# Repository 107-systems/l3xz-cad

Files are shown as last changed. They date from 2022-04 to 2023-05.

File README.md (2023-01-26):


`l3xz_cad`
==========


Hardware design files for the L3X-Z hexapod.

<p align="center">
  
</p>

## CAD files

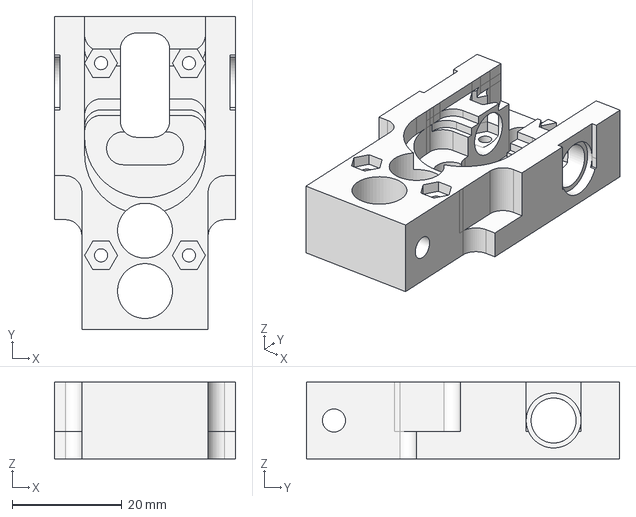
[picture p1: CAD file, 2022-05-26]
cad/dynamixel_joint.step
33.0 x 57.0 x 14.0 mm

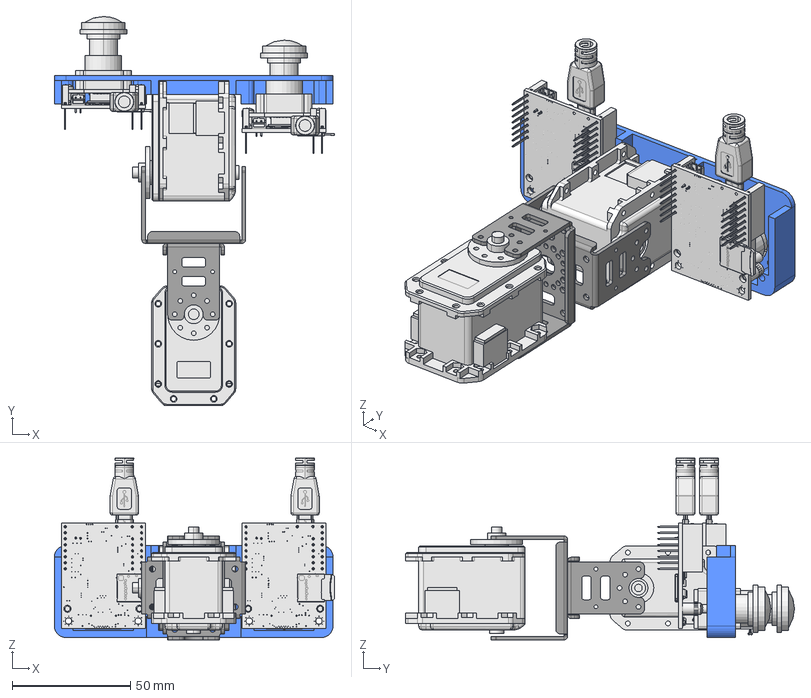
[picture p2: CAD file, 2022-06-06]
cad/pan_tilt_head/pan_tilt_head.FCStd
118.7 x 164.6 x 77.0 mm
DC07_A_DUMMY_AL
FR07-H101
FR07-H102
DC07_A_DUMMY_AL001
openmv4_h008
openmv4_h009
cam_holder001

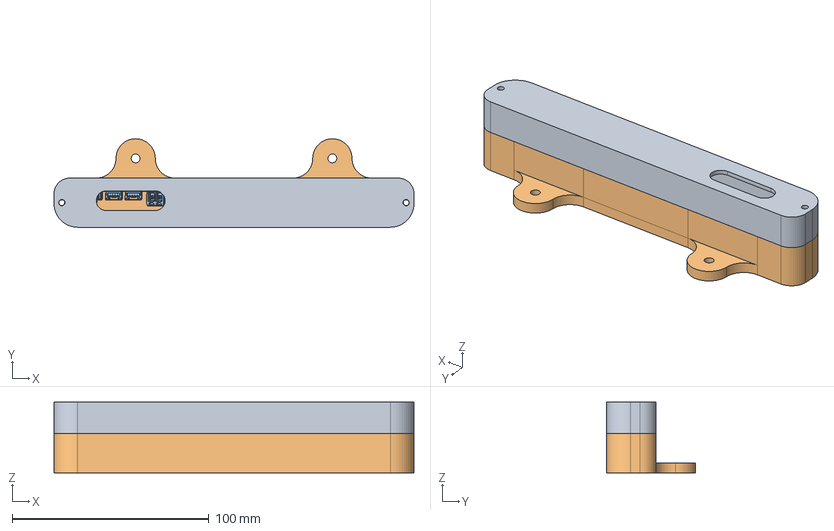
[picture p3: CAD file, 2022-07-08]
cad/radiation_sensor/radiation_sensor.FCStd
183.0 x 45.0 x 36.0 mm
radiation_sensor_top
radiation_sensor_bot
l3xz-hw_leg-controller

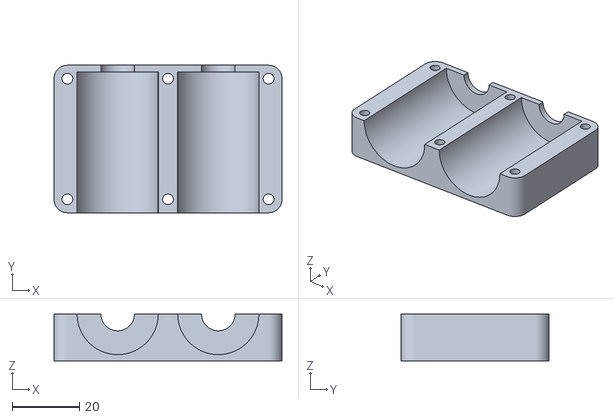
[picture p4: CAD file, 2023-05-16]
cad/stl_files/valve_mount.stl
68.0 x 44.0 x 14.0

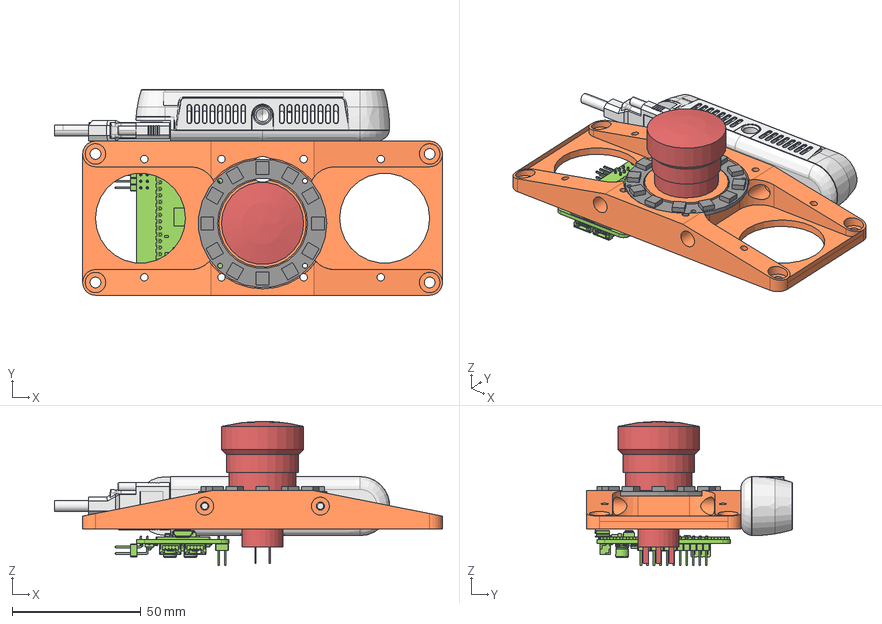
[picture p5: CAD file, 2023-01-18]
cad/upper_deck/upper_deck.FCStd
151.0 x 80.0 x 56.2 mm
Intel_RealSense_Depth_Camera_D415
upper_deck_plate
OpenCyphalPicoBase
Adafruit_Neopixel_12_50mm
TC-9219036

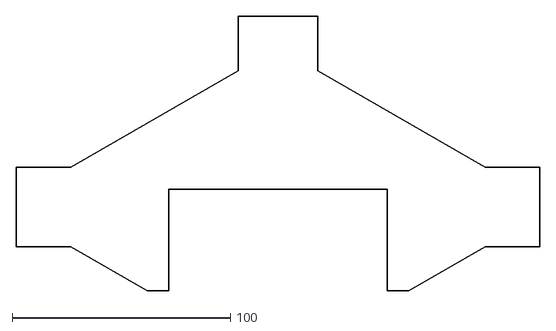
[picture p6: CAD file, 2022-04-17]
cad/body-bottom-front-bracket-base.dxf
240.0 x 125.9

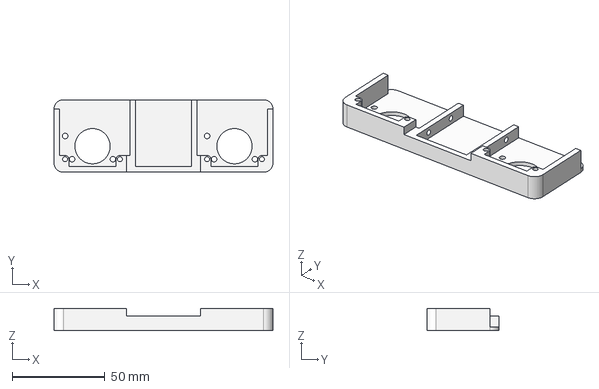
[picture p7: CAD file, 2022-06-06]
cad/pan_tilt_head/cam_holder.step
118.0 x 39.0 x 12.0 mm

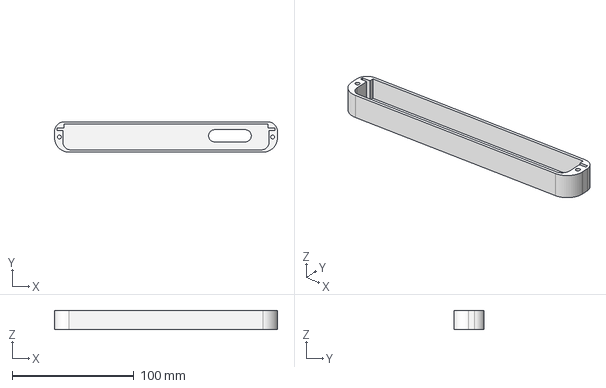
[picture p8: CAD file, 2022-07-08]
cad/radiation_sensor/radiation_sensor_top.step
183.0 x 25.0 x 16.0 mm

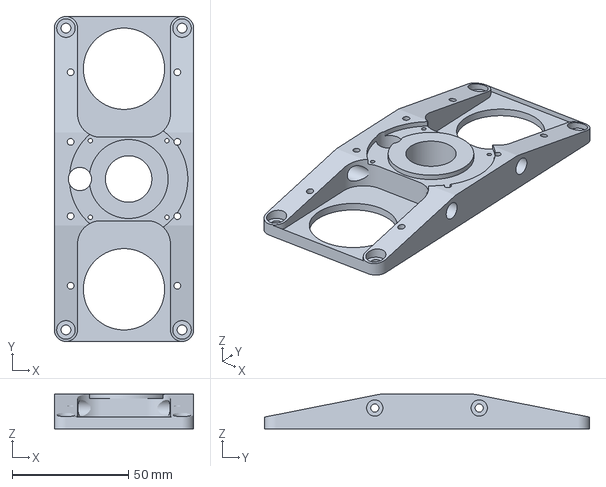
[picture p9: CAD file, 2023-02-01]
cad/stl_files/upper_deck_plate.3mf
60.0 x 140.0 x 15.0 mm

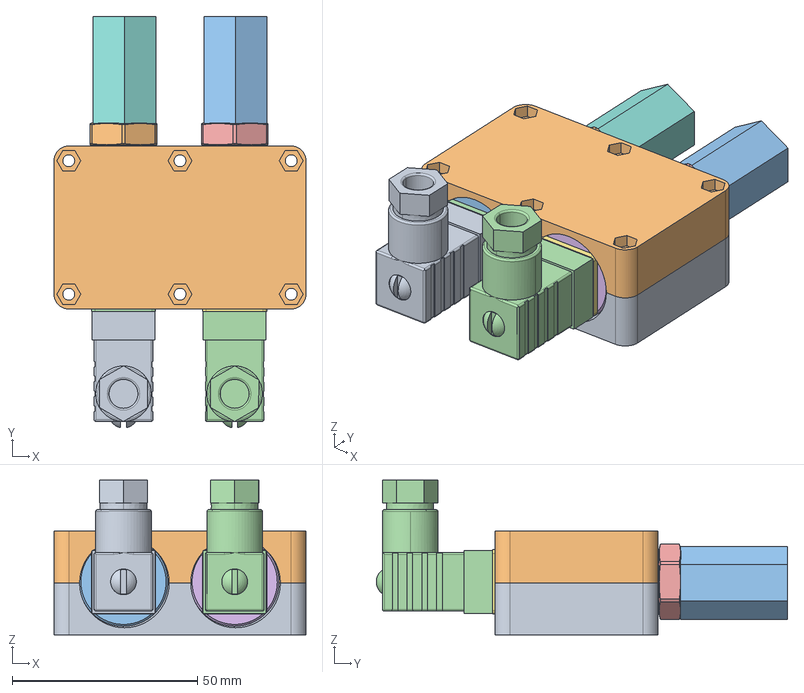
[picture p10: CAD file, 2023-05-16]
cad/valve_mount/valve_mount.FCStd
68.0 x 111.0 x 41.7 mm
Part (Mirror #1)
Small Din Connector - screw down version
B0877 iss 2
A1479 iss 2
Gasket
Small Din Connector - screw down version001
B0877 iss 003
A1479 iss 003
Gasket001

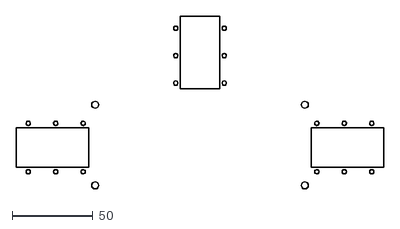
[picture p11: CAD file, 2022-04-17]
cad/body-bottom-front-bracket-holes.dxf
228.0 x 107.2

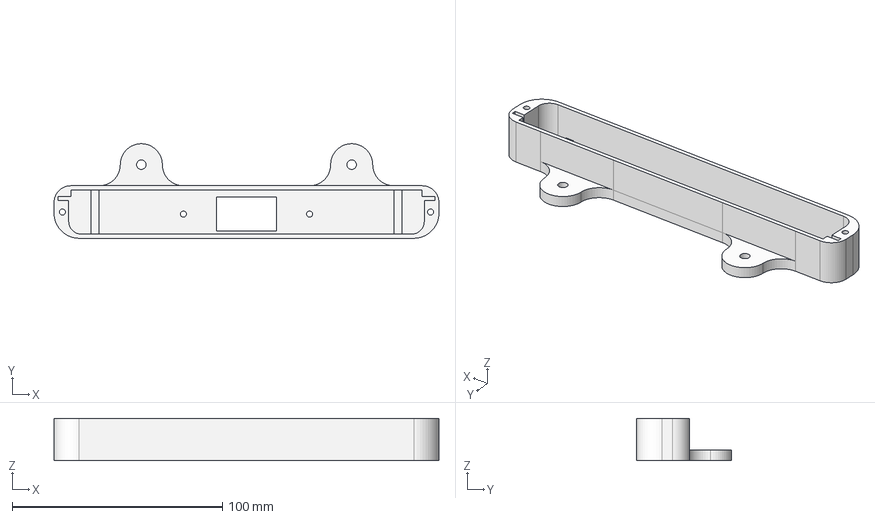
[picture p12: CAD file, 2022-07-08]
cad/radiation_sensor/radiation_sensor_bot.step
183.0 x 45.0 x 20.0 mm

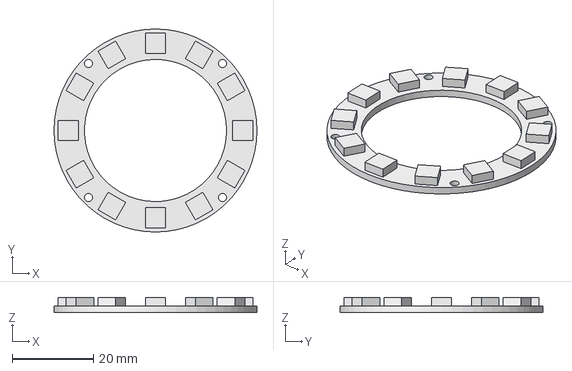
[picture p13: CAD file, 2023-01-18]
cad/upper_deck/Adafruit_Neopixel_12_50mm.step
50.0 x 50.0 x 3.60 mm

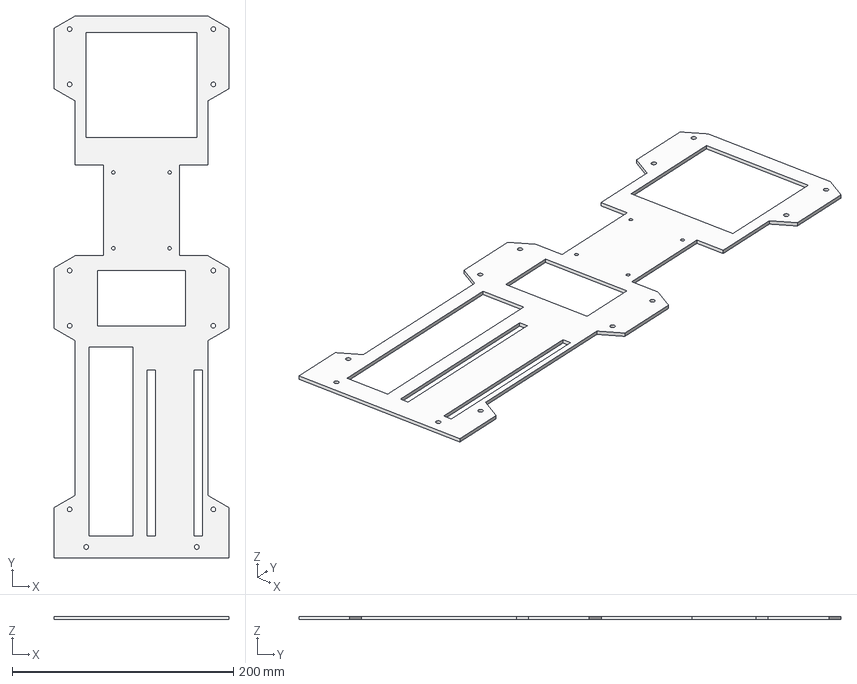
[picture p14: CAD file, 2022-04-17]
cad/top-bracket.step
158.0 x 490.2 x 3.00 mm

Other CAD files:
cad/upper_deck/upper_deck_plate.step
cad/stl_files/radiation_sensor_top.stl
cad/stl_files/radiation_sensor_bot.stl
cad/upper_deck/emergency_stop_TC-9219036.step
cad/0H108A.FCStd
cad/0H108A.step
cad/0H1650A.FCStd
cad/0H1650A.step
cad/0H506A.FCStd
cad/0H506A.step
cad/FR07-H101.stp
cad/LAS4GQH-11_S.FCStd
cad/LAS4GQH-11_S.step
cad/MX-28AT_AR.stp
cad/back-bracket.step
cad/body-bottom-back-bracket-base.dxf
cad/body-bottom-back-bracket-holes.dxf
cad/body-bottom-base.dxf
cad/body-bottom-holes.dxf
cad/body-bottom-middle-bracket-base.dxf
cad/body-bottom-middle-bracket-holes.dxf
cad/body-bottom-top-base.dxf
cad/body-bottom-top-holes.dxf
cad/body-bottom.FCStd
cad/body-bottom.step
cad/dynamixel_joint.FCStd
cad/femur.FCStd
cad/femur.step
cad/front-bracket.step
cad/l3xz.FCStd
cad/leg.FCStd
cad/leg.step
cad/middle-bracket.step
cad/pan_tilt_head/cam_holder.FCStd
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

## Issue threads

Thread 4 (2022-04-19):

ELROB Rules: Vehicle mounted Emergency Stop Unit and Warning Devices

generationmake, 2022-04-19:
https://www.elrob.org/files/elrob2022/ELROB2022_Rules_Draft.pdf

4.5.4 Vehicle mounted Emergency Stop Unit
Each vehicle must be additionally equipped with an externally actuated emergency stop capability.
Activating the emergency stop must promptly bring the vehicle into the E-stop mode, leading to an
immediate and complete stop. At least one actuator and its labelling must be easily visible and
accessible from anywhere around the vehicle. The manual emergency stop must be easy to identify
and to activate, even if the vehicle is moving at a walking pace. The operation instructions for
emergency stop actuators must be clearly labelled in English. The instructions must not be interfered
with by any other labelling or advertising.

4.5.5 Warning Devices
Each vehicle shall display one or more flashing amber warning lights, the combination of which
results in a visibility of 360 degrees azimuthally around the vehicle. The warning light(s) shall
continuously operate whenever the vehicle is switched on. The vehicle may not commence movement
until the warning light(s) have been in operation for 5 seconds.
The warning light(s) shall comply with standards for warning lights and shall not produce light that
can be confused with those of public safety vehicles such as law enforcement, fire or ambulance

Closed 2022-10-17.

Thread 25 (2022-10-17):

[Feature Request] CI - Fix spell check

aentinger, 2022-10-17:
<a href="https://107-systems.org/">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</a>

### ⚡ Feature Request

**Please Describe The Problem To Be Solved**
Due to an update of the of the spell checking action more cases are flagged than before. Address those or add the offending file to the ignore list.

aentinger, 2022-11-09:
Done by #27 .

Closed 2022-11-09.

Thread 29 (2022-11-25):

[Feature Request] Design for new pan/tilt head

aentinger, 2022-11-25:
<a href="https://107-systems.org/">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</a>

### ⚡ Feature Request

TODO ...

**Please Describe The Problem To Be Solved**

scottdarch, 2022-11-29:
Why a wireless version of the Pi Zero?

scottdarch, 2022-11-29:
Also, if reducing wire-weight is a concern then is 8-wire ethernet really going to help?

aentinger, 2022-11-30:
>Why a wireless version of the Pi Zero?

You are right, the wireless functionality will go unused. However, the issue is that currently it seems to be impossible to purchase any Raspberry Pi Zero (or W or 22) anywhere. Since @generationmake got one lying around a Raspberry Pi Zero W is what we are going to use (Bernhard, correct me if you've got another Raspberry Pi Zero type).

>Also, if reducing wire-weight is a concern then is 8-wire ethernet really going to help?

I think I mis-represented this. It's not about wire-weight but about reducing the total number of wires. And of course USB is a shitty bus for any challenging requirement.

scottdarch, 2022-12-02:
Can you point me to the (manufacturer) part numbers for the pan/tilt servos and hardware? I only saw the servo listing for the "hip" rotation on the front page.

scottdarch, 2022-12-02:
I see the two cameras are different sensors so I'm assuming this is _not_ a stereo vision pair?

scottdarch, 2022-12-02:
Putting all the compute out on the end of the pan/tilt fixture is a lot of weight to be swinging around. How about a design where just the OpenMP modules are out there (like you have today) but the PI is somewhere nearby like over the panning motor (i.e. centimeters from the sensors)?

aentinger, 2022-12-02:
>Can you point me to the (manufacturer) part numbers for the pan/tilt servos and hardware? I only saw the servo listing for the "hip" rotation on the front page.

Yes of course. The servo model of the pan/tilt servos is the same as of the hip servo: [Dynamixel MX-28AR](https://www.robotis.us/dynamixel-mx-28ar/). [Here](https://emanual.robotis.com/docs/en/dxl/mx/mx-28-2/#drawings) you can STEP files - although they might be already checked into this repository.

>I see the two cameras are different sensors so I'm assuming this is not a stereo vision pair?

Yes, you are right :wink: It's not stereo vision. One is for colour, the other one for thermal vision (a FLIR Lepton is mounted instead of a colour camera). So changing the distance between the cameras is possible, although we should try to keep it compact in terms of length as otherwise we unnecessarily constrain the range of motions, as the camera head might collide with the forward legs.

>Putting all the compute out on the end of the pan/tilt fixture is a lot of weight to be swinging around. How about a design where just the OpenMP modules are out there (like you have today) but the PI is somewhere nearby like over the panning motor (i.e. centimeters from the sensors)?

It's a good point, but not really an issue. The servos are high powered (they drive the hip joints after all) and the weight is negligible.

Also here are a couple of images of the Raspberry HAT stack with **Raspberry Pi Zero W** (It's confirmed now, @generationmake brought it by yesterday). The headers are mounted so that might be needed to take into consideration during design.

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

thirtytwobits, 2022-12-02:
Do we have step files fort the POE hat?

aentinger, 2022-12-02:
I've got none at hand, but I haven't checked yet if the manufacturer provides any. Will do that by Monday.

scottdarch, 2022-12-03:
I'm going to be a bit of a pain at first since I don't have the stock components in-hand so I have to go off of manufacturer step files and images.

I'm trying to build an assembly of the MX-28AR and the FR07-H101 bracket but there's no assembly manual and the step model of the servo is pretty low-fidelity. Can you look at the cross section I have here and tell me if I'm anywhere close to how the parts in this bracket set are put togeather?

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

scottdarch, 2022-12-03:
Does the FLIR sensor need an opening for the lens or can it image through some amount of plastic? It might be nice to design this without an opening to reduce FOD clocking up that lens.

scottdarch, 2022-12-03:
FYI, this is my go-to material for FFF printing mechanical parts: https://www.prusa3d.com/product/prusament-pc-blend-carbon-fiber-black-800g-2/ and I'll be designing to this material. It's easy to print if you have an enclosure and hardened nozzle. Just print with about 30C ambient in the enclosure and anneal if you the part will be in contact with hot surfaces.

aentinger, 2022-12-03:
> I measure about 220deg of motion available for this assembly. Can you confirm this value?

I am currently on away-from-robot so I can't guarantee a 100% but 220° of motion with a FR07-H101 bracket sounds about right 👍

aentinger, 2022-12-03:
> Does the FLIR sensor need an opening for the lens or can it image through some amount of plastic?

Yes, it needs a hole. There are IR transparent plastics but nothing that can be printed via 3D printer (to the best of my knowledge). @wuehr1999 do you know more about this?

aentinger, 2022-12-03:
> FYI, this is my go-to material for FFF printing mechanical parts: https://www.prusa3d.com/product/prusament-pc-blend-carbon-fiber-black-800g-2/ and I'll be designing for this material.

@wuehr1999 is this printable with your printer? I can order the referenced material and have it delivered to you, if needed.

wuehr1999, 2022-12-03:
Hi @aentinger,
I don't know any filament, that would be suitable for the camera hole.
I checked the parameters of the FFF prusament, and the parameters seem to fit for my 3D-printer. I think we should try it out.

scottdarch, 2022-12-04:
I can continue with the rPI+PoE solution requested here but I don't think this is a great solution for a few reasons:
1. It's really quite big. It add 65 cm<sup>3</sup> on top of the raspberry pi zero and requires eight 28AWG wires
2. it relies on pogos and test points. You are relying on the stiffness of the FR4 and the robustness of springs in the pogos to keep your Pi powered through jostles and tumbles.
3. A lot of the additional size is going to adding USB ports that you don't want.
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
scottdarch, 2022-12-10:
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

Looks like image of last year's event has a much higher upper deck then you have in your freecad document. What's the height that you want here?

scottdarch, 2022-12-10:
FYI: https://rpilocator.com/

aentinger, 2022-12-10:
Hi Scott ;) that's a useful website to know, thank you.

As for the distance I believe it to be 50mm but I'll doublecheck in around 24hrs when I'll be back from a trip.

aentinger, 2022-12-13:
>Looks like image of last year's event has a much higher upper deck then you have in your freecad document. What's the height that you want here?

The dimension is **70 mm**.

>Also, what are the FOVs for either camera?

For the colour camera: ([Source](https://openmv.io/collections/cams/products/openmv-cam-h7-r2))
* HFOV = 60.7°
* VFOV = 47.5°

For the thermal camera:
* Configurations with 25°, 50° and 57° HFOV (f/1.1 silicon doublet) ([Source](https://groupgets-files.s3.amazonaws.com/lepton/Resources/500-0659-00-09%20Rev204%20Lepton%20Engineering%20Datasheet.pdf))

scottdarch, 2022-12-24:
V1 design complete. Test prints and assembly ongoing...

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

aentinger, 2022-12-24:
> V1 design complete. Test prints and assembly ongoing...

Love the design 👍 everyone's other opinions that I sampled was equally positive 😁

scottdarch, 2022-12-24:
Totally forgot to post the link. Sorry: https://a360.co/3jv3NId

aentinger, 2022-12-25:
> https://a360.co/3jv3NId

Terrific! One question that I had from looking at the design: why is the thermal imaging set back vs the colour camera?

scottdarch, 2022-12-25:
> why is the thermal imaging set back vs the colour camera?

I've placed the focal point of of each lens at the pivot point, at least mostly (I eyeballed it). The optical camera's focal point  is further forward since it has a greater focal length. There are solids in the model for each camera's FOV so I'm confident there are no obstructions from the structures.

aentinger, 2022-12-26:
Thanks for the clarification :wink: :bow:

aentinger, 2022-12-26:
Also I had been thinking: This repository has become an unfocused storage location of various different hardware related files. How about relocating all files related to the new pan/tilt head into a dedicated repository, i.e. `l3xz-hw_pan_tilt_head`?

scottdarch, 2022-12-28:
> How about relocating all files related to the new pan/tilt head into a dedicated repository, i.e. l3xz-hw_pan_tilt_head

sure.

Test prints are going well. The tilt head is working just like I thought it would. The one error in my design is the panning. I was trying to get 140º of panning but, after adding the mechanical parts for vibe-mounting and fine-tuning the camera position I ended up with a measly 90º of panning:

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

I've designed a longer neck version that gets us back up to 130º:

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

... but it's a bit awkward looking. Not sure how you feel about it.

The other solution is a bit more radical; would you be open to changing the laser-cut decks to extend out the aluminum super-structure to move the pan servo out and under the tilt servo? For example:

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

This would give you a huge range of motion increase and the Dynamixel brackets support stacking the servos (https://www.robotis.us/fr07-x101k-set/#gallery-2)

The other question would be the lidar and if the cameras would be in the way in this new configuration:

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

aentinger, 2022-12-28:
Thank you very much for the update :wink: Love all those rendered images :rocket:

> The other solution is a bit more radical; would you be open to changing the laser-cut decks to extend out the aluminum super-structure to move the pan servo out and under the tilt servo?

To be honest, I'd rather avoid it. It would cost north of 300 € and would require to fully disassemble and reassemble the whole robot (that's what's really scaring me right now). I have a complete re-design touching everything on my roadmap, but only after ENRICH 2023.

aentinger, 2022-12-28:
Forgot to mention that the longer neck does not bother me design-wise :wink:

scottdarch, 2022-12-31:
First test assembly complete.

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

aentinger, 2023-01-01:
This looks delightfully sophisticated! 🙇 😄

scottdarch, 2023-01-31:
I'm calling the mechanical design good now. I'm just working on the wiring. I have some shorter 90-deg USB cables on order.

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

I'll try to get the design files merged into git this weekend.

aentinger, 2023-02-01:
I love it =) Looks extremely cool =)

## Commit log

2022-03-15 Uploading femur/tibia CAD files .... attention ... final drill holes for mounting "leg controller" on femur have yet to be added.
    [femur.FCStd, tibia.FCStd]
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2022-03-16 Improvements over 1st prototype.
    [femur.FCStd]
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2022-03-21 Checking in pre-eliminary bottom plate.
    [body-bottom.FCStd]
2022-03-22 Rework/Mechanical Bug Fixes.
    [body-bottom.FCStd]
2022-03-22 Final commit of base plate (order sent to Schaeffer).
    [body-bottom-base.dxf, body-bottom-holes.dxf, body-bottom.FCStd]
2022-03-22 fully constrained construction files
    [femur.FCStd, tibia.FCStd]
2022-03-22 added holes, made body
    [femur.FCStd, tibia.FCStd]
2022-03-23 made first draft of leg
    [dynamixel_joint.FCStd, dynamixel_joint.step, femur.step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]
2022-03-23 updated 3d model with dynamixel servo
    [FR07-H101.stp, MX-28AT_AR.stp, leg.FCStd]
2022-03-25 added hydraulic cylinders
    [0H1650A.FCStd, 0H1650A.step, leg.FCStd]
2022-03-25 updated the dynamixel joint
    [dynamixel_joint.FCStd, dynamixel_joint.step, leg.FCStd]
2022-03-25 added switch to leg
    [LAS4GQH-11_S.FCStd, LAS4GQH-11_S.step, leg.FCStd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]
2022-03-25 made first model of complete robot
    [body-bottom.step, l3xz.FCStd, leg.FCStd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]
2022-03-26 added drill holes in femur and tibia
    [femur.FCStd, femur.step, leg.FCStd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]
2022-03-26 added hydraulic components to 3d model
    [0H108A.FCStd, 0H108A.step, 0H506A.FCStd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]
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2022-03-28 added battery and filters to 3d model
    [l3xz.FCStd]
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2022-03-29 added first draft of pan tilt head
    [cam_holder.FCStd, cam_holder.step, pan_tilt_head.FCStd]
2022-03-29 added openmv to pan tilt head, added rendering
    [pan_tilt_head.FCStd]
2022-03-30 created 3d model of scanse sweep, added draft for upper deck
    [Scanse_Sweep.FCStd, Scanse_Sweep.step, upper_deck.FCStd]
2022-03-30 added upper deck and pan tilt head to 3d model of l3xz
    [pan_tilt_head.FCStd]
2022-03-30 Pushing back/middle/front servo brackets.
    [body-bottom-back-bracket-base.dxf, body-bottom-back-bracket-holes.dxf, body-bottom-front-bracket-base.dxf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]
2022-03-30 added brackets to design
    [back-bracket.step, body-bottom.FCStd, front-bracket.step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]
2022-04-02 added stl files for 3d print
    [dynamixel_joint.FCStd, dynamixel_joint.stl, leg.FCStd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]
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2022-04-03 added first draft of pcb to leg
    [femur.FCStd, leg.FCStd]
2022-04-04 Adding sketches for top-plate providing additional stability along the length of the whole robot.
    [body-bottom.FCStd]
2022-04-04 Adding top base/holes DXF files and FPD file.
    [body-bottom-top-base.dxf, body-bottom-top-holes.dxf, body-bottom.FCStd]
2022-04-05 updated hydraulic cylinders with correct dimensions
    [0H1650A.FCStd, 0H1650A.step, leg.FCStd]
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2022-04-17 updated pcb in leg
    [leg.FCStd]
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2022-04-17 updated dynamixel joint AGAIN
    [dynamixel_joint.FCStd, dynamixel_joint.step, dynamixel_joint.stl]
2022-04-17 added dynamixel joint to leg model
    [leg.FCStd]
2022-04-22 made dynamixel joint super massive
    [dynamixel_joint.FCStd, dynamixel_joint.step, dynamixel_joint.stl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]
2022-04-30 added 3d model and stl file for upper deck plate
    [upper_deck.FCStd, upper_deck_plate.FCStd, upper_deck_plate.step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]
2022-05-01 added mounting place for Scanse Sweep adapter PCB, added 4 Adafruit NeoPixel LEDs, updated design and stl files.
    [Adafruit_Neopixel.FCStd, Adafruit_Neopixel.step, Scanse_Sweep_Adapter.FCStd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]
2022-05-22 added counter nuts, increased diameter of lower shaft, made hole for bearing, updated step and stl
    [dynamixel_joint.FCStd, dynamixel_joint.step, dynamixel_joint.stl]
2022-05-22 added pocket to place washer
    [dynamixel_joint.FCStd, dynamixel_joint.step, dynamixel_joint.stl]
2022-05-23 updated cam holder to be more solid
    [cam_holder.FCStd, cam_holder.step]
2022-05-23 updated cam holder and pan tilt head 3d model, added stl file
    [cam_holder.FCStd, cam_holder.step, cam_holder.stl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]
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2022-05-26 added more freedom to dynamixel joint
    [dynamixel_joint.FCStd, dynamixel_joint.step, dynamixel_joint.stl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]
2022-05-26 corrected orientation of stl file
    [dynamixel_joint.FCStd, dynamixel_joint.stl]
2022-05-27 completely reworked cam holder
    [cam_holder.FCStd, cam_holder.step, pan_tilt_head.FCStd]
2022-05-27 added holes for LEDs
    [cam_holder.FCStd, cam_holder.step, cam_holder.stl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]
2022-05-27 added holes for LEDs again
    [cam_holder.FCStd, cam_holder.step, cam_holder.stl]
2022-05-27 rotated cam holder and openmv cam by 180 degrees
    [pan_tilt_head.FCStd]
2022-07-08 added enclosure for radiation sensor
    [radiation_sensor.FCStd, radiation_sensor_bot.FCStd, radiation_sensor_bot.step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]
2022-07-08 added radiation sensor to complete 3d model
    [radiation_sensor.FCStd]
2022-07-08 Add CI workflow to check for commonly misspelled words
    On every push, pull request, and periodically, use the codespell-project/actions-codespell action to check for commonly
    misspelled words.
    In the event of a false positive, the problematic word should be added, in all lowercase, to the ignore-words-list field
    of ./.codespellrc. Regardless of the case of the word in the false positive, it must be in all lowercase in the ignore
    list. The ignore list is comma-separated with no spaces.
2022-10-25 Fix CI spellchec (#27)
    Ignore `cad` and `doc` subfolders.
2023-01-14 reworked upper deck because lidar is no longer available
    [upper_deck_plate.FCStd]
2023-01-14 updated stl and step files
    [upper_deck_plate.FCStd, upper_deck_plate.step, upper_deck_plate.stl]
2023-01-14 changed hole for emergency stop to 19 mm, updated production data
    [upper_deck_plate.FCStd, upper_deck_plate.step, upper_deck_plate.stl]
2023-01-14 updatedmodel of complete upper deck
    [upper_deck.FCStd, upper_deck_plate.step]
2023-01-14 added emergency stop and neopixel ring
    [Adafruit_Neopixel_12_50mm.FCStd, Adafruit_Neopixel_12_50mm.step, emergency_stop_TC-9219036.FCStd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]
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2023-02-01 Adding PrusaSlicer project files.
    [upper_deck_plate.3mf]
2023-05-08 added first draft of valve mount
    [valve_mount.FCStd, valve_mount.stl]
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2023-05-15 added step model for pressure sensor
    [67092.stp, valve_mount.FCStd]
